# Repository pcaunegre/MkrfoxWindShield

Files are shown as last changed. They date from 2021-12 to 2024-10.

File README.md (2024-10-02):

# MkrfoxWindShield
Arduino Mkrfox1200 interface to wind sensors

## About this project
    
OpenWindMap is a network of wind sensors (https://www.openwindmap.org), 
collecting data from the devices via the Sigfox network.

This project is about building a device (hardware and software) to process 
the measurements from commercial wind sensors and send data via Sigfox 
messages (8 bits every 10min). The device is powered by a small battery and
a solar panel (power management is included on the shield).

This project has a broader scope than the former one (https://github.com/pcaunegre/SWiM) because:
- it supports 3 types of commercial sensors
- it includes a Printed Circuit Board (PCB) design to go as a shield for the Arduino Mkrfox1200
  so that the complete device can be quickly assembled without soldering 

I have a few shields left that I can distribute upon request (pascal.caunegre AT gmail.com)

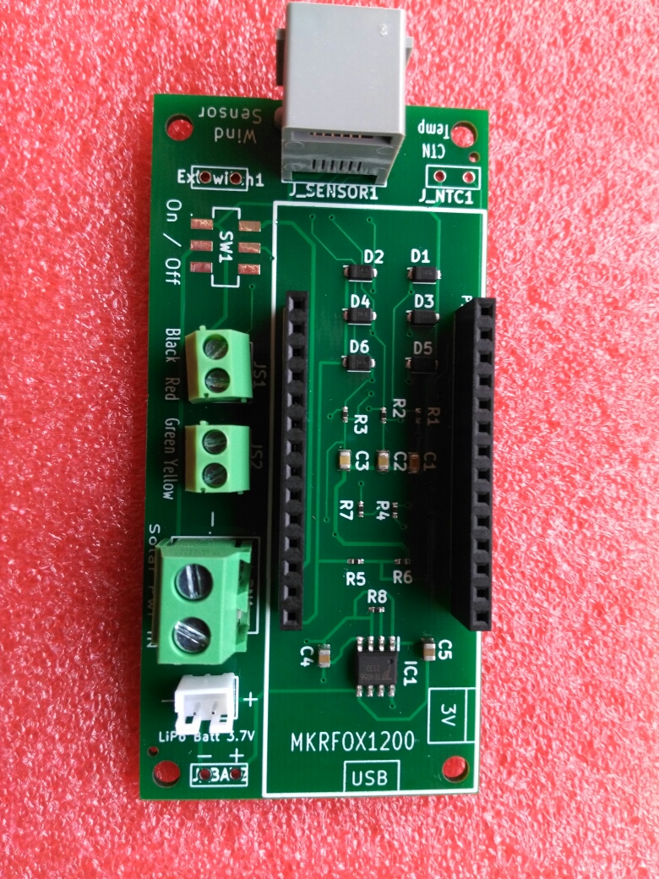
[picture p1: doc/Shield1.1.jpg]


## This project includes several independant modules:

### Hardware
    
The hardware is an Arduino shield compatible with the MKRFOX1200 board.
All material (schematics, layout, docs) are provided here.
The shield provides an interface with one among three types of wind sensors:
- Davis
- Peet Bros
- MiSol (Shenzen)

### Software 
    
The software automatically identifies the sensor type, controls the wind sensor 
and sends measures via Sigfox.
If the device is registered by the OpenWindMap network, measures will appear 
on the web (http://www.openwindmap.org/)

Please read the [manual](doc/Manual.pdf) for more information.

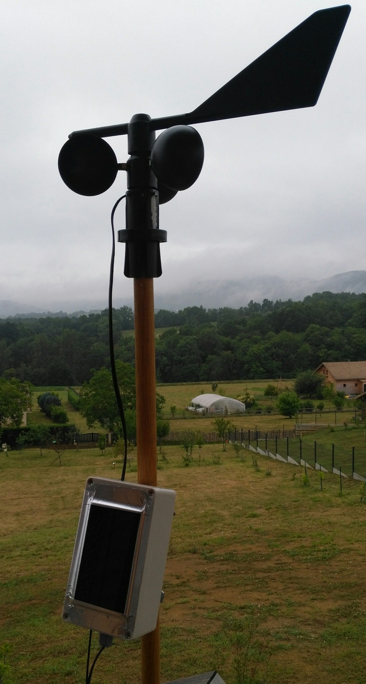
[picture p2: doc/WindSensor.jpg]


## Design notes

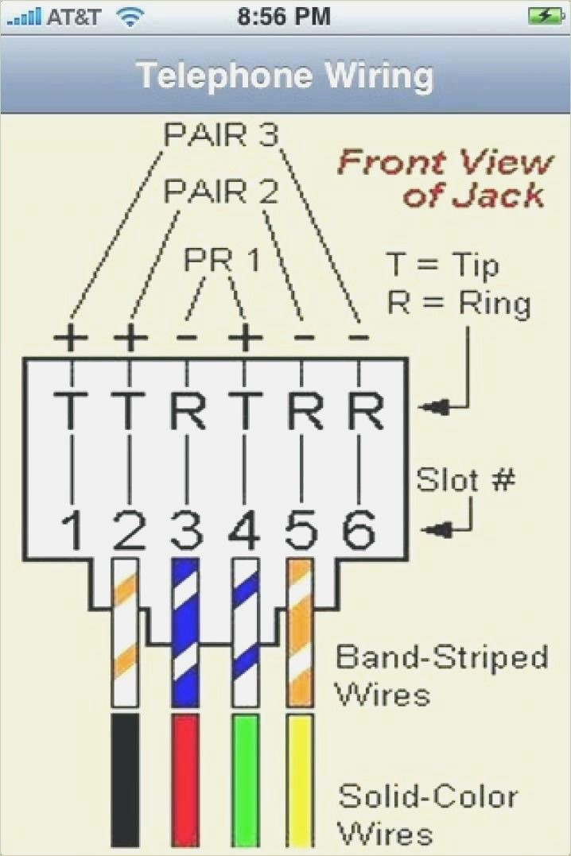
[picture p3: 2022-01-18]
doc/6RJ11.jpg

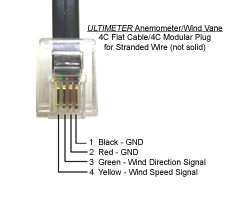
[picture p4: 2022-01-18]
doc/PeetConn.png

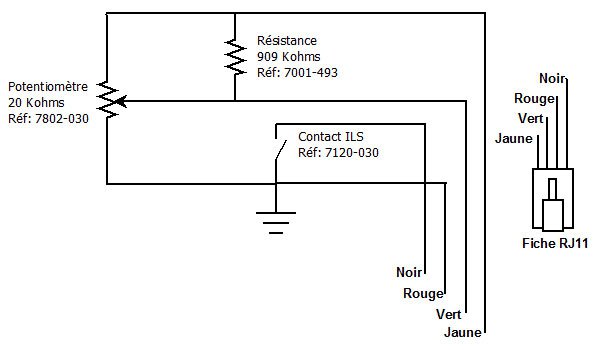
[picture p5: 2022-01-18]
doc/DavisConn.jpg

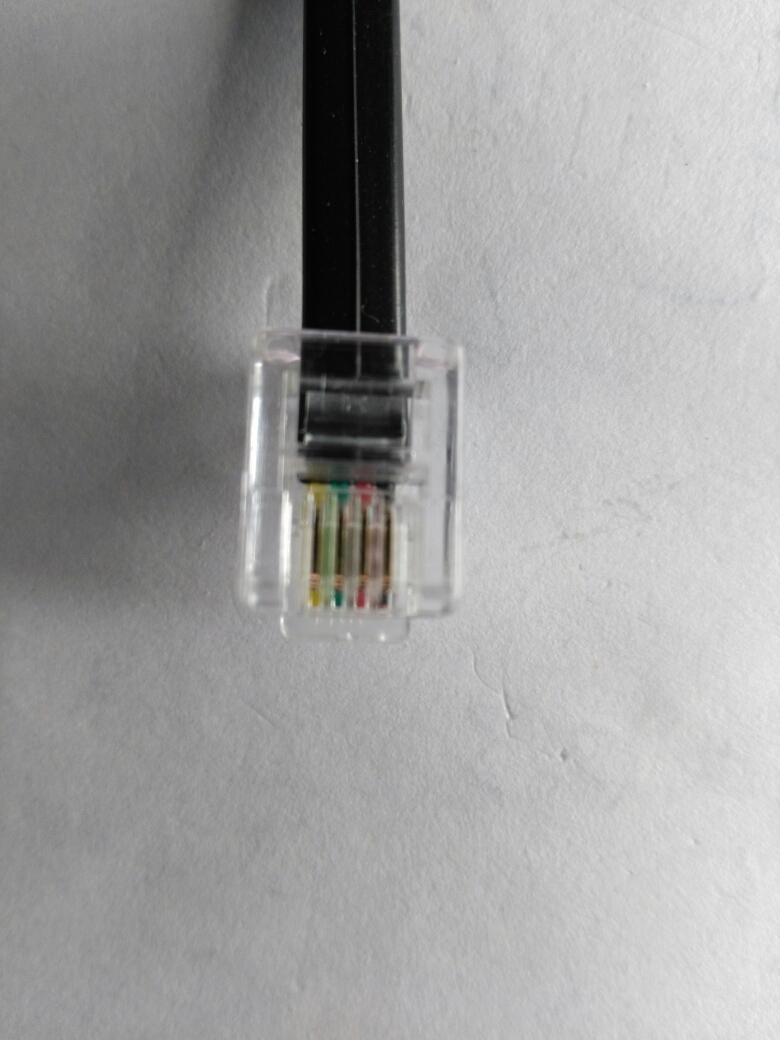
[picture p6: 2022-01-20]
doc/RJ11.jpg

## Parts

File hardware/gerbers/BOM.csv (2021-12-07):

Comment | Designator | Footprint | LCSC Part Number | MFR part number
10nF 10% 50V | C1,C2,C3 | 0805 | C1710 | CL21B103KBANNNC | SMD
10uF 10% 16V | C4,C5 | 0805 | C95841 | CL21B106KOQNNNE
Diode schottky 40V 1A | D1,D2,D3,D4,D5,D6 | SOD-123 | C169540 | 1N5819W
TP4056-42-ESOP8 | IC1 | ESOP-8_EP_3.9x4.9x1.27P | C16581 | TP4056-42-ESOP8
1k 1% 1/16W | R1,R2,R3 | 0402 | C11702 | 0402WGF1001TCE
10k 1/16W 1% | R4,R7 | 0402 | C25744 | 0402WGF1002TCE
390k 1% 1/16W | R5 | 0402 | C25782 | 0402WGF3903TCE
100k 1/16W 1% | R6 | 0402 | C25741 | 0402WGF1003TCE
20k 1/16W 1% | R8 | 0402 | C25765 | 0402WGF2002TCE
Switch 6V 300mA | SW1 | SMD | C221666 | JS202011SCQN
P=3.5mm Screw terminal | JS1,JS2 | CONN-TH_P3.50_KF350-3.5-2P | C474892 | KF350-3.5-2P | Hand soldered
2.54mm 14 Straight 1 Receptacle Through Hole | P1,P2 | HDR-TH_14P-P2.54-V | C124407 | B-2200S14P-A120
2 Header PH 0.079"(2.00mm) Male Pin Through Hole Wire To Board | J_BAT1 | CONN-TH_PH-2A | C8886 | PH-2AK
P=5.08mm Screw terminal | J_PV1 | CONN-TH_2P-P5.00_WJ500V-5.08-2P | C8465 | WJ500V-5.08-2P
DS1133-S60APS | J_SENSOR1 | RJ11-TH_PCB-6P6C-90 | C77857 | DS1133-S60APS

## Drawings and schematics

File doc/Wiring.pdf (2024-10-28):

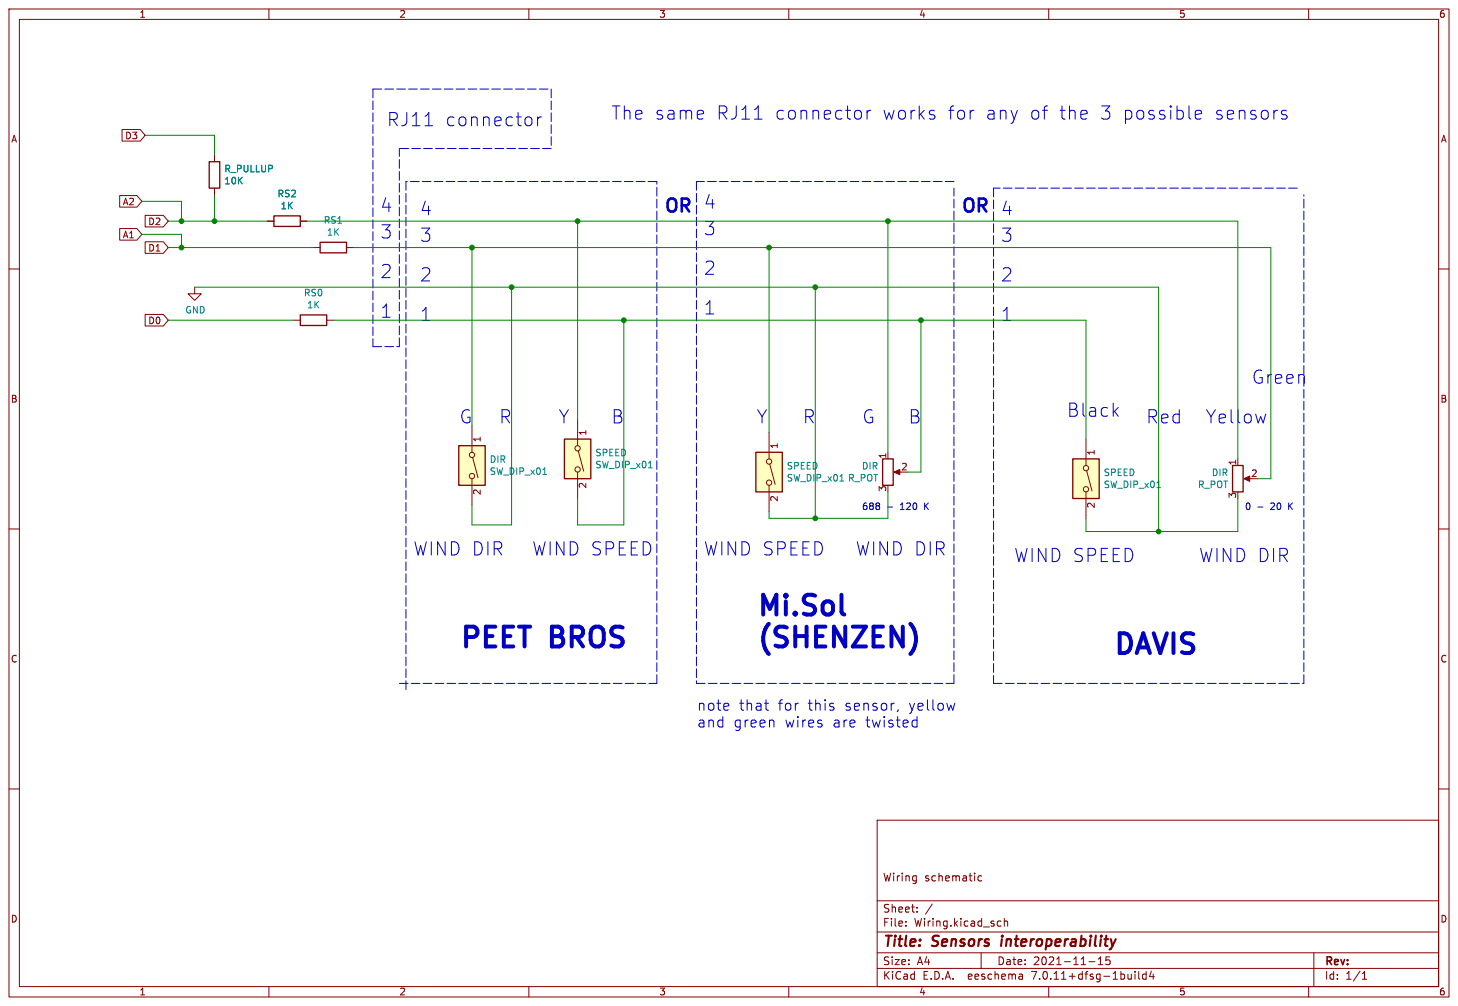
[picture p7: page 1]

File: Wiring.kicad_sch Sheet: / Wiring schematic

Id: 1/1 Title: Sensors interoperability

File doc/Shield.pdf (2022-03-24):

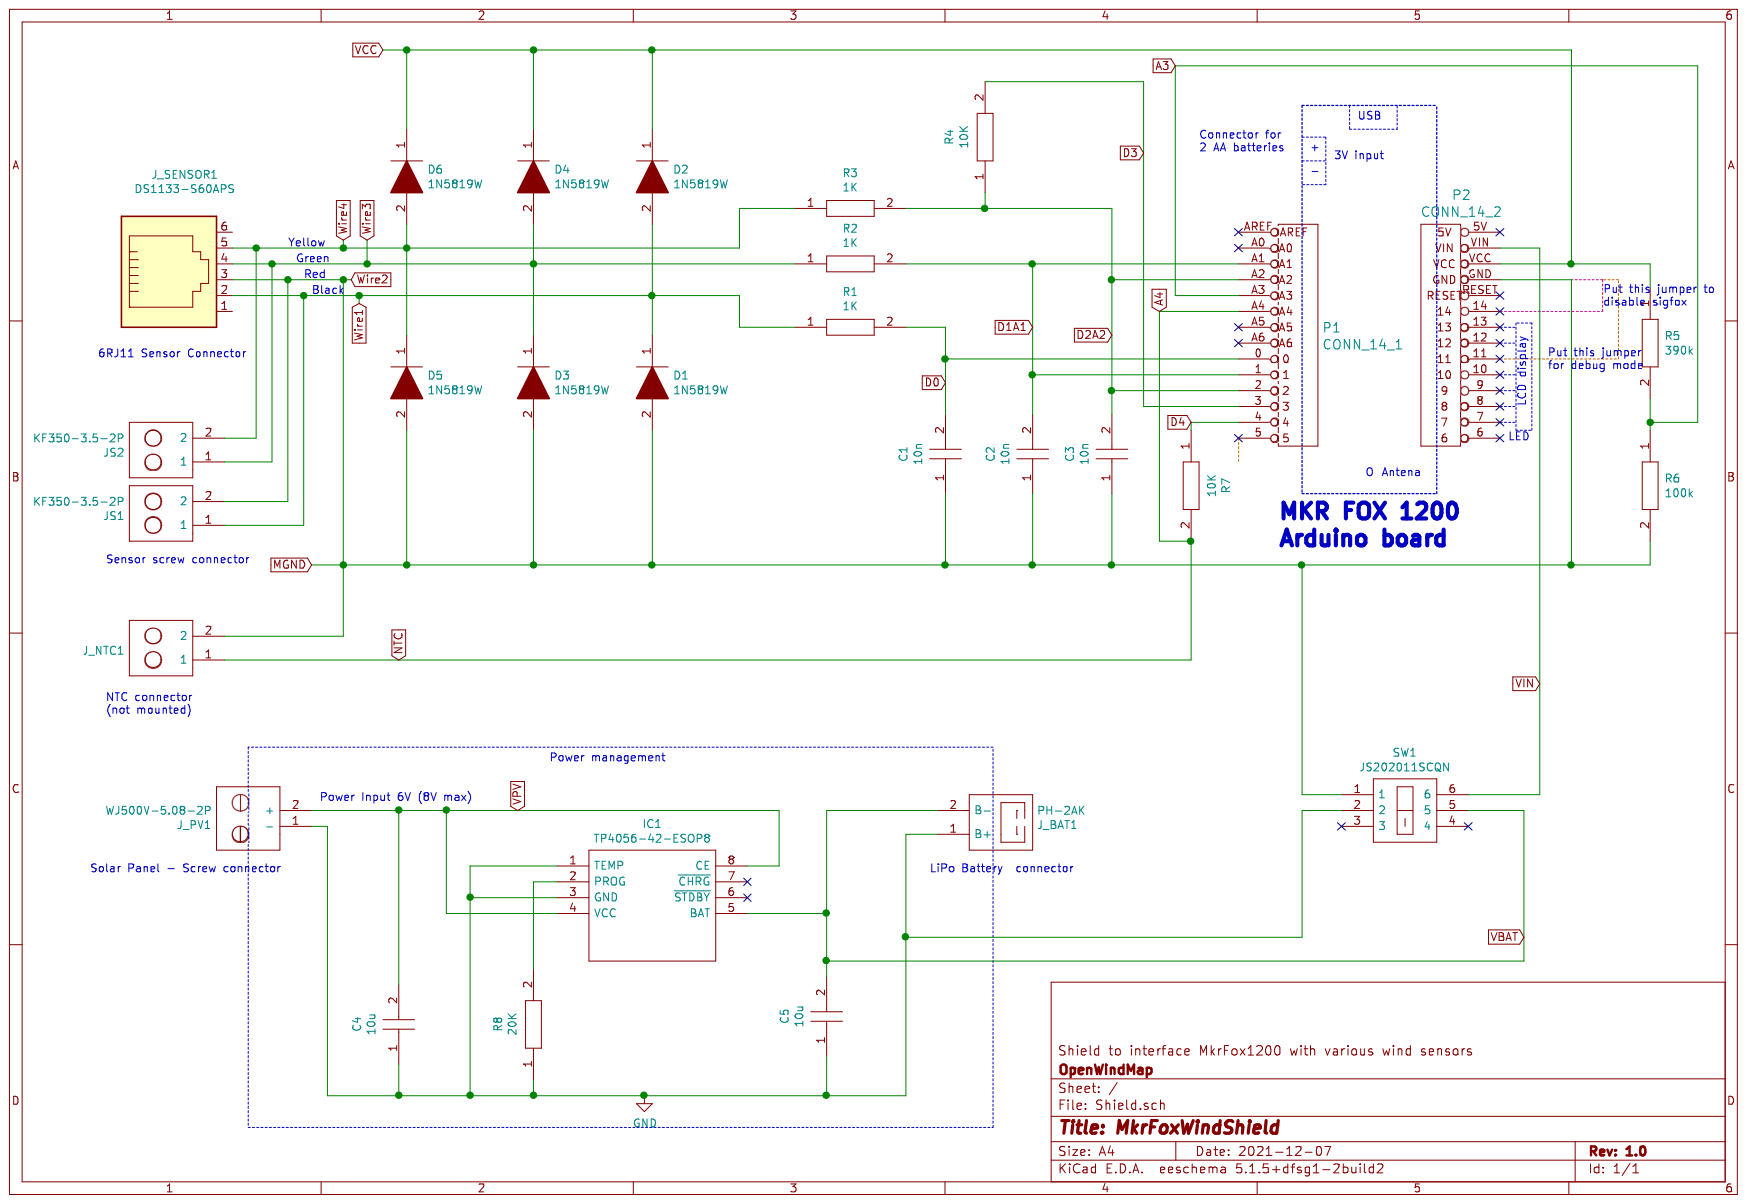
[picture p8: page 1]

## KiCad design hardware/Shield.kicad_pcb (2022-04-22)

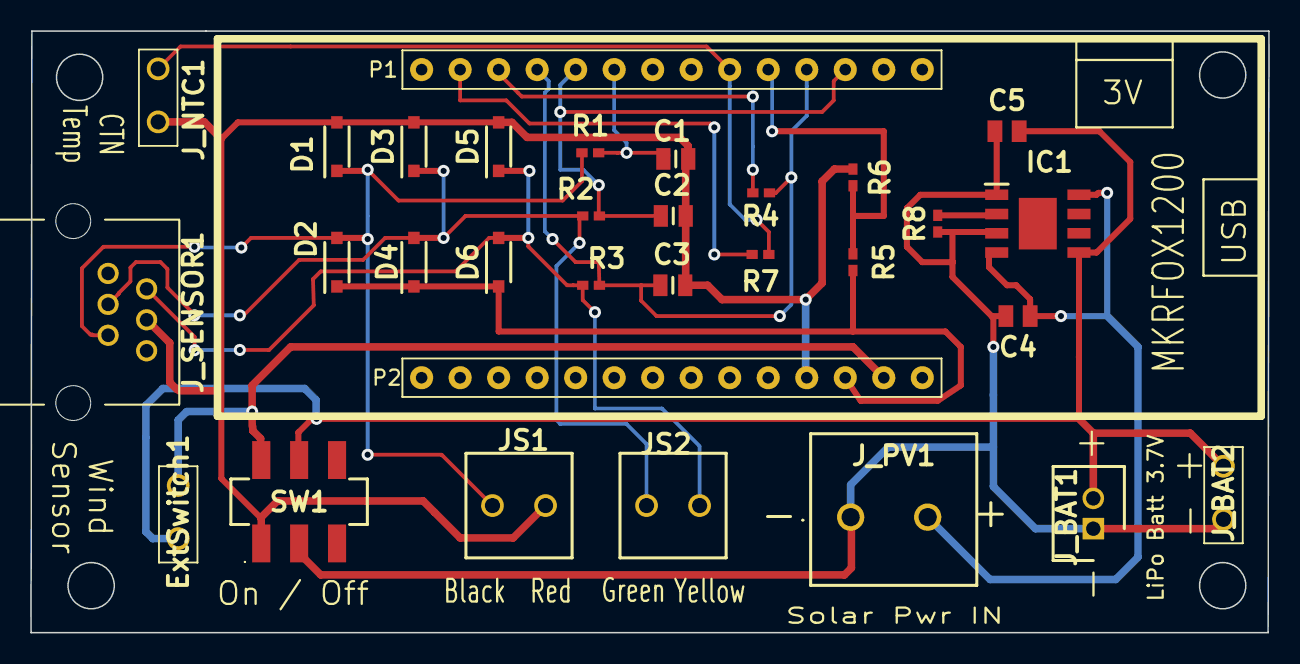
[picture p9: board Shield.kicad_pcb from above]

Board: 2 copper layers, 81.6 x 39.7 mm, 31 parts (0 on the bottom side), 17 nets.

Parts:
C1, C2, C3: 10n; CAPC2012X65N
C4, C5: 10u; CAPC2012X140N
D1, D2, D3, D4, D5, D6: 1N5819W; SODFL3516X120N
ExtSwitch1: KF350-3.5-2P; SolderPoints
IC1: TP4056-42-ESOP8; SOIC127P600X175-9N
JS1, JS2: KF350-3.5-2P; KF350352P
J_BAT1: PH-2AK; SHDR2W52P0X200_1X2_600X460X630P
J_BAT2: KF350-3.5-2P; SolderPoints
J_NTC1: KF350-3.5-2P; SolderPoints
J_PV1: WJ500V-5.08-2P; WJ500V5082P
J_SENSOR1: DS1133-S60APS; DS1133S60APS
P1: CONN_14_1; CONN14_FP1
P2: CONN_14_2; CONN14_FP2
R1, R2, R3: 1K; RESC1005X40N
R4, R7: 10K; RESC1005X40N
R5: 390k; RESC1005X40N
R6: 100k; RESC1005X40N
R8: 20K; RESC1005X40N
SW1: JS202011SCQN

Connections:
A3: P1.A3, R5.2, R6.1
A4: J_NTC1.1, P1.A4, R7.2
D0: C1.2, P1.0, R1.2
D1A1: C2.2, P1.1, P1.A1, R2.2
D2A2: C3.2, P1.2, P1.A2, R3.2, R4.1
D3: P1.3, R4.2
D4: P1.4, R7.1
GND: C4.1, C5.1, IC1.1, IC1.3, J_BAT1.1, J_BAT2.2, J_PV1.1, R8.1, SW1.2
MGND: C1.1, C2.1, C3.1, D1.2, D3.2, D5.2, JS1.2, J_NTC1.2, J_SENSOR1.3, P2.GND, R6.2, SW1.1
unnamed: IC1.2, R8.2
VBAT: C5.2, ExtSwitch1.2, IC1.5, J_BAT1.2, J_BAT2.1, SW1.5
VCC: D2.1, D4.1, D6.1, P2.VCC, R5.1
VIN: ExtSwitch1.1, P2.VIN, SW1.6
VPV: C4.2, IC1.4, IC1.8, J_PV1.2
Wire1: D1.1, D2.2, JS1.1, J_SENSOR1.2, R1.1
Wire3: D3.1, D4.2, JS2.1, J_SENSOR1.4, R2.1
Wire4: D5.1, D6.2, JS2.2, J_SENSOR1.5, R3.1

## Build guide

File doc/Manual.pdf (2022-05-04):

# MkrfoxWindShield manual

pascal.caunegre@gmail.com, Mai 4, 2022

## Building your own wind sensor station

This manual shows how to build an OpenWindMap-compatible wind station.
Refer to https://www.openwindmap.org for more information on this network (previously known as Pioupiou).

## You will need to gather the following parts:

- One of the three possible sensors:

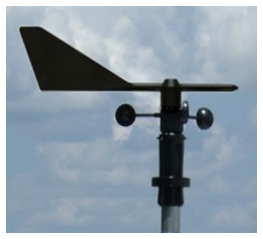
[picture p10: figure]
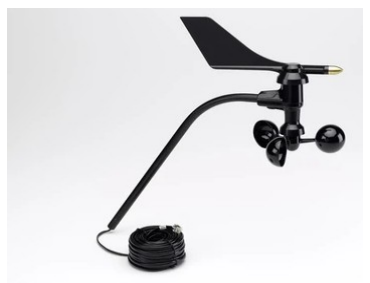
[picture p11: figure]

- The MkrfoxWindShield (version 1.1 on the picture)

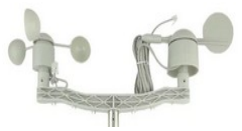
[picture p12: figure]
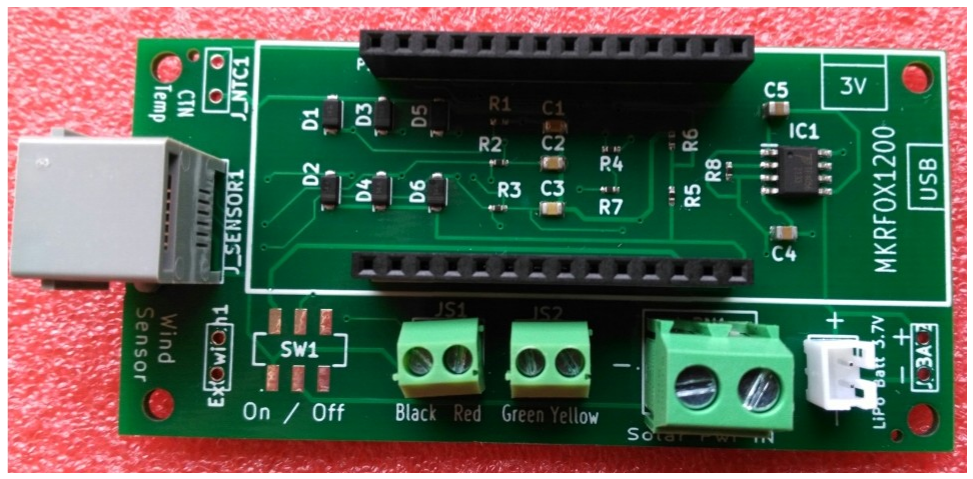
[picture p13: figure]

(the author can resell some boards if available, otherwise you can fabricate them with schematics and part list given in hardware/ directory of this project)

Davis | Peet Bros | Mi.Sol (Shenzen)

OR

OR

- A MkrFox1200 Arduino board

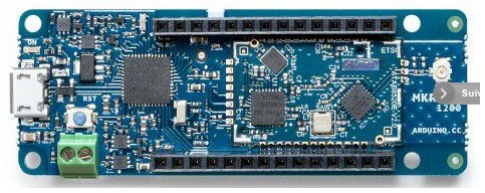
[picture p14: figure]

- A 868 Mhz Antenna
- Either batteries or solar panel

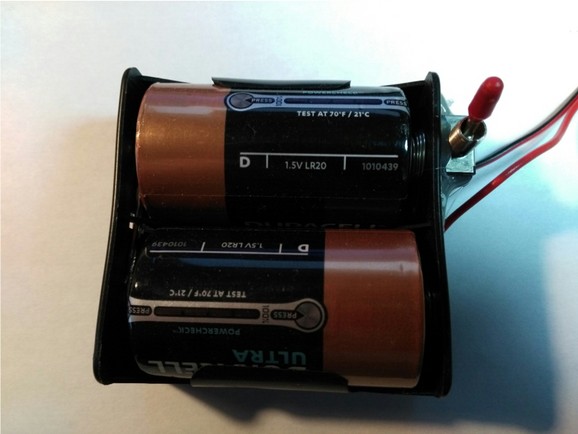
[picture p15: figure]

(note: 1.5V batteries will last about a year while solar panel solution will not need maintenance)

## Uploading the station software

Your MkrFox1200 needs a software to operate the wind sensor. But first you need to read internal board IDs with a specific program. Process as follows:

- If necessary, install the Arduino software (IDE) on your computer.
- Download all code files from the github: https://github.com/pcaunegre/MkrfoxWindShield/tree/main/src/firmware
- Connect the board to your computer by a USB cable

Board ID reading:
- Open the src/board_infos/board_infos.ino file from the IDE
- Double click on the board reset button, the yellow led is dimmed and blinks, meaning the board is ready to receive the program
- Click the upload button from the IDE
- Open the Serial monitor
- The ID and PAC values will be printed. Note them down.

A set of two 1.5V Batteries

OR

A Solar Panel (5V, 0.5W) + a LiPo 3.7V battery

Registration of the board through OpenWindMap network
Send the board IDs you have noted down to OpenWindMap through the forum.
You will get a station ID in return.
Your measurements will be available through http://www.openwindmap.org/<ID>
Note: it is important to register the board via OWM (and not directly via Sigfox server) because it allows benefiting the group contract and shares your measurements with the community.

Final software installation:
Important: Don’t do this before your station is registered in OpenWindMap because this step will trigger a Sigfox message dispatch. (Alternately, you can put a jumper between the pin GND and pin 14 to disable the Sigfox messages.)
- Open the src/firmware/firmware.ino file from the IDE
- Double click on the board reset button, the yellow led is dimmed and blinks, meaning the board is ready to receive the program
- Click the upload button from the IDE
- The led should then blink frankly 10 times and then switch off.
- Your board is ready, disconnect it from USB.

## Assembling parts

Assemble the various parts and install them into a rainproof box. To assemble you will have to:
- Plug the MkrFox1200 on top of the wind shield.
- Connect the antenna through the coaxial RF socket.
- If you use 1.5V batteries, connect them through the MkrFox1200 screw connector (take care of the polarity). Preferably use solar panel+Lipo battery, by connecting them on the wind shield (solar panel on screw connector, battery on the white socket).
- Connect your wind sensor either by plugging the RJ11 jack or by connecting the wires by the screw connector (from left to right):
- for Davis and Peet sensors: connect 1: black wire, 2: red, 3: green, 4: yellow
- for MiSol: | connect 1: black wire, 2: red, 3: yellow, 4: green

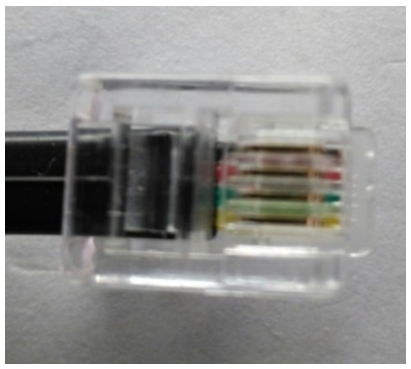
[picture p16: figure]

Notes about v1.1 of the board

- There are 2 holes to solder an external switch (in this case, do a solder point between the pads above the “on” mark)
- There are 2 holes to solder the battery (instead of using the connector)
- J_NTC1 is to solder a 10k NTC for optional temperature measurement (but software get temperature only
once a day)

## Starting the wind sensor

Now that all components are connected together, let’s switch on the system.
- If using the Lipo battery, turn the shield switch on
- If using 1.5V batteries the power is on as soon as you place the batteries in their harness The board will boot and you will see 10 flashes of the yellow led.
Then you will see 1, 2 or 3 long flashes. They mean that the system identifies your sensor.
1 flash means Davis sensor, 2 flashes means Peet sensor, and 3 flashes means MiSol sensor.
If the sensor recognition is wrong, the led desperately blinks. Verify the sensor connection, move a bit the wind vane position and push the reset button.
If the led keeps blinking, this means that the sensor is wrongly connected or the sensor type is not recognized or has any default.
The sensor starts immediately the measurements (1 measure every 3s). Every 5 minutes, minimum, maximum and average wind speed and average wind direction values are computed. After 10 minutes, the 2 sets of previous measurements are send to Internet via Sigfox network.
It means that 10 min after power up you should see your measurements on OpenWindMap site.
SpotAir (https://www.spotair.mobi) will also reflect the same measurements after a little time (about a day) without any action from you.

## Debug mode

You can put a jumper between GND and Pin 11 to enter the debug mode. In this mode, if you connect the board via the USB cable and read the USB input from your computer, the measurements will be printed. To read the USB input, use the serial monitor from the Arduino IDE.
If you want to capture values in a file, you can use this Python script: __________________________________________________________________________

#!/usr/bin/python3

## Script to listen serial port and write contents into a file for debug purpose

## requires pySerial to be installed ( pip3 install pyserial )

# call it

# serialListen.py [ <filename.csv> ]

import serial
from datetime import datetime import sys
import time

now = datetime.now()
dt_string = now.strftime("%H:%M")

n=len(sys.argv)
if n>1:
write_to_file_path=sys.argv[1]
else:
write_to_file_path = "Imeas" + dt_string +".csv"

serial_port = '/dev/ttyACM0';
baud_rate = 9600; #In arduino, Serial.begin(baud_rate)

output_file = open(write_to_file_path, "w+")

while True:
try:
ser = serial.Serial(serial_port, baud_rate) break
except:
time.sleep(1)

while True:
line = ser.readline();
line = line.decode("utf-8") #ser.readline returns a binary, convert to string print(line);
output_file.write(line)
output_file.flush()
__________________________________________________________________________

## Admin reports

When you switch on the wind sensor and once a day, an admin report is sent.
The admin report can be seen here: https://api.pioupiou.fr/v1/sigfox-messages/<ID>
An admin report is a data of 12 bytes, e.g.:

Only the 4 last bytes (8 characters) encode the admin report with the following infos:
byte 9 | : | battery voltage (by adding 199.5 and dividing by 100)
byte 10 | : | temperature ( by substracting 50.5)
byte 11 | : | sensor type (10=Davis, 20=Peet bros, 30=MiSol Shenzen)
byte 12 | : | software version

Example of python script to decode the admin report: #!/usr/bin/python3
import sys
entry=sys.argv[1]
print("Soft = %d" % int(entry[22:24],16))
print("Sensor = %d" % int(entry[20:22],16))
print("Temp = %d" % (int(entry[18:20],16)-50.5)) print("Vbatt = %f" % ((int(entry[16:18],16)+199.5)/100.0))

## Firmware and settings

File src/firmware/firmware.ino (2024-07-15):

/*
*
*  Main program to control the MKRFOX 1200 board
*
*  Able to interface with Davis, Peet Bros or Shenzen device.
*
*
*
*/

#include <SigFox.h>
#include <math.h>
#include "def.h"



unsigned long  last_sampleT  ;  // last time in millis a measure sampling has been done
unsigned long  last_reportT  ;  // last time in millis a report has been done

int            max_wspeed    ;  // max wind speed over the sample period
int            min_wspeed    ;  // min wind speed over the sample period
int            cnt_ws_samples;  // count the number of samples we have to compute speed avg
int            cnt_wd_samples;  // count the number of samples we have to compute dir avg
int            acc_wspeed    ;  // wind speed accumulator to compute avg
float          acc_wdX       ;  // accumulate wind dir projection on X axis (cos)
float          acc_wdY       ;  // accumulate wind dir projection on X axis (sin)
int            prevWindDir   ;  // memorize the last dir in case we cannot compute new one (speed too low)
int            statReportCnt ;  // counter : every 2 hits data are sent thru sigfox 
SigfoxWindMessage_t msg      ;  // create an instance of the struct to receive the wind data frame
int            sentrepnbr=0  ;  // nbr of report sent

float          vinMax=0.0    ;  // max VCC voltage over a daily period
float          vinMin=0.0    ;  // min VCC voltage over a daily period
float          tmpMax=0.0    ;  // min Temperature over a daily period
float          tmpMin=0.0    ;  // min Temperature over a daily period
float          vinSum=0.0    ;  // sum of VCC voltage over a daily period
float          tmpSum=0.0    ;  // sum of Temperature over a daily period
int            mdCnt=0       ;  // nbr of monitoring elements
int            firstsmp=1    ;  // first sample token

int            cpudiv        ;  // value of cpu freq divisor

bool           debugmode = false; // 1=debug mode
bool           sigfox_en = true ; // enable sigfox
int            repnbr=0;          // used in debug
int            msnbr=0;           // used in debug
int            monitoringReportNbr=0; // number of sent monitoring report

int sensor=0;          // sensor number


void setup() {
  
  int blinknbr=SOFTVERSION; // e.g. blinks 12 times for version 1.2
  // a jumper between 12 and GND will disable sigfox
  pinMode(SIGDISAB,INPUT_PULLUP); 
  sigfox_en = digitalRead(SIGDISAB);

  // a jumper between 10 will enable led blink
  pinMode(TESTPIN,INPUT_PULLUP); 

  cpudiv = CPU_FULL;
  
  // a jumper between 11 and GND will enable debug mode
  pinMode(DEBUGPIN,INPUT_PULLUP); 
  pinMode(Led,OUTPUT); // led used for debug or at power up
  
  if (digitalRead(DEBUGPIN) == 0) {
    debugmode=true;  
    blinkLed(5,400/cpudiv); // blinks 5 times to indicate debug mode
    delay(3000);    // waiting 3s to allow launching usb serial on PC
  }

  debugInit(sigfox_en,debugmode);
  blinkLed(blinknbr,400/cpudiv); // say hello n flashes

    
  // device detection at boot
  if (sensor == 0) {
    delay(3000);
    detectSensorType();  // will set the sensor variable
  } 
  
  // device initialization
  switch (sensor) {
    case DAVIS:
      Davis_setup();    break;
    case PEET:
      Peet_setup();     break;
    case SHENZEN:
      Shenzen_setup();  break;
    default:
      // say detection failed: blink 1000 times and reboot
      blinkLed(1000,500/cpudiv);
      reboot();
  }
  sendInitialReport();
  statReportCnt    = 0;
  prevWindDir      = -1;
  repnbr           = 0;
  reset_stat(); 
  if (!debugmode) set_cpu_speed(CPU_SLOW);
  last_sampleT     = millis();
  last_reportT     = millis();
  sentrepnbr=0;
    
}


void loop() {

  if (sensor>0) {
    
    // normal operation
    unsigned long now = millis();
    unsigned long dt1 = now - last_sampleT;  // ellapsed time since last sample
    unsigned long dt2 = now - last_reportT;  // ellapsed time since last report
    
    // if it's time to sample, get measures and store for stats
    if (dt1 > SAMPLING_PERIOD/cpudiv) {
      noInterrupts();
      int ws  = -1;
      int wd  = -1;
      switch (sensor) {
        case DAVIS:
          ws=Davis_takeWspeed(dt1);
          wd=Davis_takeWdir();
          break;
        case PEET:
          ws=Peet_takeWspeed();
          wd=Peet_takeWdir();
          Peet_resetSampler();       
          break;
        case SHENZEN:
          ws=Shenzen_takeWspeed(dt1);
          wd=Shenzen_takeWdir();        
          break;
        default:
          // NOT initialized: run init procedure
          // TBD
          break;
      }
      // drop out the first sample
      if (firstsmp==0) store_for_stat(ws,wd);
      firstsmp=0; 
      debugPrintMeasure(ws,wd);         
      // when pin low, led blinks to show activity
      if (digitalRead(TESTPIN)==0) { blinkLed(1,300/cpudiv); } 
      last_sampleT = millis();
      interrupts();
    }
    
    if (dt2 > (REPORT_PERIOD/2)/cpudiv) {
      // at every sigfox report period we send 2 packets of data
      // so at every half-report period we store data     
      if (digitalRead(TESTPIN)==0) { blinkLed(2,300/cpudiv); }  
      makeReport();
  
      // clear stats
      reset_stat();
      last_reportT = millis();
      last_sampleT = millis();
    }

    if (now > REBOOT_PERIOD/cpudiv) {
      debugPrintMsg("REBOOTING");
      reboot(); // avoid managing millis value wrapping (every 2**32-1 ms)
    }
  }  

}

/*
 * Take measures and compute some statistics over a report period
 * min, max, accumulate for average, mean wind dir
 * 
*/
void store_for_stat(int ws, int wd)  {
  // wind speed in km/h
  // wind dir in degrees
  // -1 means meas not valid  
  if (ws>-1)  {
    if (ws > max_wspeed)  max_wspeed = ws;
    if (ws < min_wspeed)  min_wspeed = ws;
    acc_wspeed += ws;
    cnt_ws_samples++;
  
    if (wd>-1)  {
      // projection of direction is weighted by the speed
      acc_wdX += ws * cos(PI*wd/180.);
      acc_wdY += ws * sin(PI*wd/180.);
      cnt_wd_samples++;
    }
  } 
}

/*
 * Resets all counters and accumulator when a report has been done
 * min, max, accumulate for average, mean wind dir
 * 
*/
void reset_stat()  {
  max_wspeed    = 0  ;
  min_wspeed    = 999;
  acc_wspeed    = 0  ;
  cnt_ws_samples= 0  ;
  cnt_wd_samples= 0  ;
  acc_wdX       = 0.0;
  acc_wdY       = 0.0;
  firstsmp      = 1;
}

/*
 * Computes avg wind speed
*/
int wspeed_avg()  {
  SERIAL.print("sum WS =");SERIAL.println(acc_wspeed);
  SERIAL.print("Nbr WS =");SERIAL.println(cnt_ws_samples);
  
  //debugPrint("sum WS =",acc_wspeed);
  //debugPrint("cnt WS =",cnt_ws_samples);
  return(int(acc_wspeed/cnt_ws_samples));
}

/*
 * Computes avg wind direction
*/
int wdir_avg()  {    
  int avgdir;
  // when no dir samples, keep the previous direction
  if (!cnt_wd_samples) return(prevWindDir);

  if (acc_wdY==0.0 && acc_wdX==0.0)  {
    // when speed is null over the whole period, we cannot compute the avg direction
    avgdir=prevWindDir;
  } else {
    avgdir = int(atan2(acc_wdY,acc_wdX)*180/PI);
    if (avgdir<0)  avgdir += 360;
    prevWindDir = avgdir;   // store this in a globvar
  }  
  return(avgdir);
}

/*
*
*  Data Report creation/dispach
*
*/
void makeReport() {

  int avws, avwd, ret;

  noInterrupts();
  debugPrintMsg ("Report ");
  storeMonitoringData();
    
  // report the values
  avws = wspeed_avg();
  avwd = wdir_avg();
  debugPrintAvgMeas(avws,avwd);
  
  // store in msg structure with OpenWindMap-expected data encoding
  msg.speedMin[statReportCnt]     = encodeWindSpeed(min_wspeed);
  msg.speedAvg[statReportCnt]     = encodeWindSpeed(avws);
  msg.speedMax[statReportCnt]     = encodeWindSpeed(max_wspeed);
  msg.directionAvg[statReportCnt] = encodeWindDirection(avwd); 
  
  SERIAL.print("msg Min (");SERIAL.print(statReportCnt);SERIAL.print(") = ");SERIAL.println(min_wspeed);
  SERIAL.print("msg Avg (");SERIAL.print(statReportCnt);SERIAL.print(") = ");SERIAL.println(avws);
  SERIAL.print("msg Max (");SERIAL.print(statReportCnt);SERIAL.print(") = ");SERIAL.println(max_wspeed);
  SERIAL.print("msg DIR (");SERIAL.print(statReportCnt);SERIAL.print(") = ");SERIAL.println(avwd);
    
  interrupts();

  // we send telegram half the time
  if (statReportCnt==1) {
    // every ADMIN_REPORT_FREQ reports, we send a monitoring report
    statReportCnt=0;
    if (sentrepnbr >= ADMIN_REPORT_FREQ) {
      sentrepnbr = 0;
      addMonitoringInfos();
      ret=sendSigFoxMessage(12);
      debugPrint("  Monitoring rep sent: ",ret);
    } else {
      // send sigfox telegram this time
      debugPrint("Make Rep NBR = ",sentrepnbr);
      ret=sendSigFoxMessage(8);
      sentrepnbr++;
      debugPrint("  Normal report sent: ",ret);
    }
  } else {
    // sigfox telegram will be next turn
    statReportCnt=1;
    debugPrintMsg("  Next time");
  }

}

/*
*
*  get and store Vin and Temp measures for monitoring report
*
*/
void storeMonitoringData() {
  float vin=getBatteryVoltage(VINMEAS);
  float tmp=getTemperature();
  vinSum += vin;
  tmpSum += tmp;
  if (vin>vinMax) vinMax=vin;  
  if (vin<vinMin) vinMin=vin;  
  if (tmp>tmpMax) tmpMax=tmp;  
  if (tmp<tmpMin) tmpMin=tmp;
  mdCnt++;      
}

/*
*  reset variables used by monitoring report
*/
void clearMonitoringData() { 
  vinMax=0.0;  vinMin=9999; vinSum=0.0;
  tmpMax=-99;  tmpMin=99;   tmpSum=0.0;
  mdCnt=0;      
}

/*
*  add supplementary infos into report for monitoring purpose
*
* Data:   vinMax vinMin vinAvg tmpMax tmpMin tmpAvg nbr   notused VIN   VCC   TEMP  SENS+SoftV 
* Bytes:  1,2    3,4    5,6    7,8    9,10   11,12  13,14 15,16   17,18 19,20 21,22 23,24 
*/
void addMonitoringInfos() {

  // include stat infos collected over the period
  // by using the 8 first bytes for different purpose
  monitoringReportNbr++; 
  msg.speedMin[0] = encodeVoltage(vinMax);
  msg.speedMin[1] = encodeVoltage(vinMin);
  msg.speedAvg[0] = encodeVoltage(vinSum/mdCnt);
  msg.speedAvg[1] = encodeTemperature(tmpMax);
  msg.speedMax[0] = encodeTemperature(tmpMin);
  msg.speedMax[1] = encodeTemperature(tmpSum/mdCnt);
  msg.directionAvg[0] = mdCnt;
  msg.directionAvg[1] = monitoringReportNbr; 
  clearMonitoringData(); // reset the values
  
  float vcc=getBatteryVoltage(VCCMEAS); // measure VCC (when 3V battery is used)
  // not possible with hardware h1.1: 
  // requires 390k resistor between VIN and A5 + 100k between A5 and GND
  float vin=getBatteryVoltage(VINMEAS); // measure VIN (real Lipo batt voltage)
  float  tp=getTemperature();

  msg.batVin      = encodeVoltage(vin);    // VIN measure (if wired)
  msg.batVcc      = encodeVoltage(vcc);    // VCC measure
  msg.temperature = encodeTemperature(tp); // Temperature (if sensor wired)
  // encode sensor+softversion in one Byte : b = s<<6 + v
  // 2 bits for sensor, 6 bits for softversion 
  // decode with s=b>>6, v=b&63
  msg.version     = (uint8_t)((sensor/10)<<6)+SOFTVERSION; // Sensor type DAVIS=10 PEET=20 MISOL=30 
  
  debugPrint("batVin  ",(uint8_t)msg.batVin);
  debugPrint("batVcc  ",(uint8_t)msg.batVcc);
  debugPrint("temp    ",(uint8_t)msg.temperature);
  debugPrint("version ",(uint8_t)msg.version);
  debugPrint("Admin RPT",sensor);
}


/*
*  send the monitoring message at reboot
*/
void sendInitialReport() { 
  // dummy values for init for easy message retrieving
  msg.speedMin[0]     = 0;  msg.speedMin[1]     = 0;
  msg.speedAvg[0]     = 0;  msg.speedAvg[1]     = 0;
  msg.speedMax[0]     = 0;  msg.speedMax[1]     = 0;
  msg.directionAvg[0] = 0;  msg.directionAvg[1] = 0;
  addMonitoringInfos();
  int ret=sendSigFoxMessage(12);  // send initial monitoring report
  debugPrint("Initial rep sent: ",ret);
  SERIAL.println(millis());
}
    
/*
*  Utility to find out which sensor is connected
*  period in millis
*
*/
void blinkLed(int times, int period) {
  for (int i=0; i<times; i++ ) {
    digitalWrite(Led,HIGH);
    delay(period);
    digitalWrite(Led,LOW);
    delay(period);
  } 
}

/*
 * system functions
*/
void reboot() {
  NVIC_SystemReset();
  while (1);
}

/*
 * CPU underclocking: clock is divided by divisor
*/
void set_cpu_speed(int divisor){
  cpudiv=divisor;
  GCLK->GENDIV.reg = GCLK_GENDIV_DIV(divisor) |         // Divide the 48MHz clock source by divisor 48: 48MHz/48=1MHz
                   GCLK_GENDIV_ID(0);            // Select Generic Clock (GCLK) 0
  while (GCLK->STATUS.bit.SYNCBUSY);               // Wait for synchronization      
}

/*
*
*  Utility to find out which sensor is connected
* 
*  We power up the lines through 2 configurations and measure the analog value on A2
*  Based on the resistor dividers, tolerances, we have thresholds to identify the sensor.
*
*/
void detectSensorType() {
  
  String mess="";
  analogReadResolution(ADCBITS);
  analogReference(AR_DEFAULT);
  pinMode(SENSPPIN,OUTPUT); // sensor potentiommeters are powered by this pin
  digitalWrite(SENSPPIN,HIGH);
    
  // step 1 : D2R, D0R
  pinMode(2,INPUT);
  pinMode(0,INPUT);
  delay(500);
  int val1 = analogRead(A2);
 
  // step 2 : D2R, D0W0
  pinMode(2,INPUT);
  pinMode(0,OUTPUT);
  digitalWrite(0,LOW);
  delay(500);
  int val2 = analogRead(A2);
  
  //stop powering sensor
  pinMode(0,INPUT_PULLUP);
  digitalWrite(SENSPPIN,LOW);

  if (val1 > THR1)  {
    // can be shenzen or peet
    if (val2 > THR1) { 
      // we have peet sensor
      sensor=PEET;
      blinkLed(sensor/10,1500/cpudiv); // say Peet detected
    } else if ((val2 > THR_Shenzen_low) && (val2 < THR_Shenzen_hi)) {
      // confirm we have shenzen sensor
      sensor=SHENZEN;
      blinkLed(sensor/10,1500/cpudiv); // say Shenzen detected
    } else if (val2 < THR_Peet_hi) {
      // Peet when dir switch is closed
      sensor=PEET;
      blinkLed(sensor/10,1500/cpudiv); // say Peet detected
    } else {
      sensor=-1;
      mess="Detection issue between shenzen and peet";
    }
    
  } else if ((val1 > THR_Davis_low) && (val1 < THR_Davis_hi)) {
    // confirm we have Davis  
    if ((val2 > THR_Davis_low) && (val2 < THR_Davis_hi)) {
      // val2 should not differ from val1
      sensor=DAVIS;
      blinkLed(sensor/10,1500/cpudiv); // say Davis detected
    } else {
      sensor=-1;
      mess="Detection issue with Davis";
    }
  } else {
    sensor=-1;
    mess="Sensor Detection issue";
  }
  debugSensorDetection(mess,sensor,val1,val2);

}

/*
*  Utility to measure Battery voltage, return mV
*/
float getBatteryVoltage(int vpin) {

  analogReadResolution(ADCBITS);
  analogReference(AR_INTERNAL1V0);
  delay(100);
  float vb=(analogRead(vpin)/(ADCFS*VBDIV))*1000.0; // read vbat through k~1/5 divider so v=adc/(k*adcfs)
  debugPrintVbat(vpin,vb);
  analogReference(AR_DEFAULT);  // restore to the default ref used in other parts of the code
  delay(100);
  return(vb);

}

/*
*  Utility to measure temperature
*/
float getTemperature() {
  
  analogReadResolution(12);      
  analogReference(AR_DEFAULT); // to give a ratio of the resistor divider
  pinMode(4,OUTPUT);
  digitalWrite(4,HIGH);
  delay(100);
  int adc=analogRead(A4);
  
  analogReadResolution(ADCBITS);
  digitalWrite(4,LOW);
  delay(100);
  
  float Rnorm=(1.0/((4095.0/adc)-1.0));    // R pull up of 10k
  float tp=1.0/(log(Rnorm)/BETA+1.0/TEMP25)-273.15; // temp in Celsius
  debugPrintTemp(tp);
  return(tp);

}


/*
 * functions dedicated to Sigfox message sending
 * 
 *speedMin[0], speedMin[1], speedAvg[0], speedAvg[1], speedMax[0], speedMax[1], dirAvg[0], dirAvg[1]
 *
 * message len=8 for a normal measure transmission, 12 for an admin transmission
*/
int sendSigFoxMessage(int len) {

  int status=0; 
  if (digitalRead(SIGDISAB)) {
    debugPrint("Sending SFX Msg ",len);
    set_cpu_speed(CPU_FULL);
    // Start the module  
    delay(10);
    //SigFox.begin();
    if (!SigFox.begin()) {
      debugPrintMsg("SigFox begin error");
//       reboot();
    }
    // Wait at least 30mS after first configuration (100mS before)
    delay(100);
    SigFox.debug();

    // Clears all pending interrupts
    SigFox.status();
    delay(1);
    SigFox.beginPacket();
    
    // OpenWindMap specific data frame  
    SigFox.write((uint8_t*)&msg, len); 
    status = SigFox.endPacket();    
    SigFox.end();
    if (!debugmode) set_cpu_speed(CPU_SLOW);
 
  } else {
    debugPrint("Sigfox disabled ",len);
  }
  return(status);
}

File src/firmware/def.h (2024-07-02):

#define SOFTDATE 20240701
#define SOFTVERSION 22


#define DAVIS       10   // sensor numbering
#define PEET        20   // sensor numbering
#define SHENZEN     30   // sensor number


#define Led LED_BUILTIN  // warning: Led uses pin D6 !
#define ARRAYLEN    120  // size of an array to store pulses (40rps gives 120 values in 3s)

#define CPU_FULL   1     // normal cpu rate (48Mhz)
#define CPU_SLOW   16    // divided by 16 so 3Mhz for power saving, so we have ~3.1mA and a peak of ~45mA during 3s every 10min

// periods in ms and multiple of CPU_SLOW (16)
#define SAMPLING_PERIOD          2992    // instantaneous wind is measured on a 3s period (common rule) so 2992ms to be a modulo 16 (clock divider)
// #define REPORT_PERIOD          600000UL  // in production, report period is 10min=600s (both the period to avg the wind speed and the sigfox report period)
#define REPORT_PERIOD          592000UL  // in production, report period is 10min=600s (both the period to avg the wind speed and the sigfox report period)
#define ADMIN_REPORT_FREQ         143    // after 143 measure reports we send a monitoring report
#define REBOOT_PERIOD         604800000UL  // reboot micro every 7 day

#define VCCMEAS    A3           // Analog Pin to measure VCC voltage
#define VINMEAS    A5           // Analog Pin to measure VIN voltage

#define SERIAL   Serial         // Serial connection for debug
#define DEBUGPIN   11           // Pin to detect debug mode (when low)
#define SIGDISAB   12           // Pin to disable sigfox messages (when low)
#define TESTPIN    10           // Pin to enable led to monitor activity (when low)

#define SENSPPIN   3            // Pin to power up the sensor 
#define RPULLUP    10.0         // Pullup in kOhm
#define RSERIAL    1.0          // Same value for RS1, RS2, RS3 in kOhm
#define ADCBITS    10           // Using default ADC setup is enough
const int ADCFS =  (1<<ADCBITS)-1; // ADC full scale = 2**10-1
#define TOL        0.07          // Tolerance on R values (7%): 5% was not enough

#define VBDIV      0.20         // Res Divider to measure Vbat (100k/(100k+400k))

#define RSHENMIN   0.688        // Min value of Dir Potentiometer (Shenzen sensor) in kOhm
#define RSHENMAX   120.0        // Max value of Dir Potentiometer (Shenzen sensor) in kOhm

#define RDAVISPOT  20.0         // Dir Potentiometer (Davis sensor) in kOhm

#define UNDEFINED  -1           // Return code for undef
#define SHORT_ERR  -2           // Error code when a short is detected
#define OPEN_ERR   -3           // Error code when a open is detected

#define TEMP25    298.15        // Temp 25 ref for CTN
#define BETA     3988           // Beta Coeff of CTN TDK B57863S0103+040 https://docs.rs-online.com/6a46/0900766b813c0ed3.pdf

/*
* Threshold computation
*/

/* D2 IN, D0 OUT 0, READ A2 */
/* Peet bros detection*/
/* if speed switch open */
const int THR1=int(ADCFS*0.97);                                                            // 992
/* if speed switch closed */
const int THR_Peet_low = int(ADCFS/(1+RPULLUP/(2*RSERIAL)*(1+TOL)/(1-TOL)));               // 156
const int THR_Peet_hi  = int(ADCFS/(1+RPULLUP/(2*RSERIAL)*(1-TOL)/(1+TOL)));               // 185

/* Shenzen detection*/
const int THR_Shenzen_low = int(ADCFS/(1.0+RPULLUP/(2*RSERIAL+RSHENMIN)*(1+TOL)/(1-TOL))); // 200
const int THR_Shenzen_hi  = int(ADCFS/(1.0+RPULLUP/(2*RSERIAL+RSHENMAX)*(1-TOL)/(1+TOL))); // 952

/* Davis detection*/
const int THR_Davis_low = int(ADCFS/(1.0+RPULLUP/(RSERIAL+RDAVISPOT)*(1+TOL)/(1-TOL)));    // 670
const int THR_Davis_hi  = int(ADCFS/(1.0+RPULLUP/(RSERIAL+RDAVISPOT)*(1-TOL)/(1+TOL)));    // 714



/*
* This part of code is about packing data to comply with the format expected by OpenWindMap
*
* Numbers are arranged to fit into 8 bytes (2 periods, 4 data)
* xxx[0] -> data from T-12 to T-6 min
* xxx[1] -> data from T-6 min to T
* T being the time of emission
*/
typedef struct __attribute__ ((packed)) sigfox_wind_message {
        int8_t speedMin[2];
        int8_t speedAvg[2];
        int8_t speedMax[2];
        int8_t directionAvg[2];
        int8_t batVin;
        int8_t batVcc;
        int8_t temperature;
        int8_t version; 
} SigfoxWindMessage_t;


// wind speed encoding over 1 byte
// 
static uint8_t encodeWindSpeed (float speedKmh) {
  uint8_t encodedSpeed;
  if (speedKmh < 10.) {
    // 0 to 9.75 kmh : 0.25 km/h resolution
    encodedSpeed = (uint8_t)(float)(speedKmh * 4. + 0.5);
  } else if (speedKmh < 80.) {
    // 10 to 79.5 kmh  : 0.5 km/h resolution
    encodedSpeed = (uint8_t)(float)(speedKmh * 2. + 0.5) + 20;
  } else if (speedKmh < 120.) {
    // 80 to 119 kmh  : 1 km/h resolution
    encodedSpeed = (uint8_t)(float)(speedKmh + 0.5) + 100;
  } else if (speedKmh < 190.) {
    // 120 to 188 kmh  : 2 km/h resolution
    encodedSpeed = (uint8_t)(float)(speedKmh / 2. + 0.5) + 160;
  } else {
    // 190 or + : out of range
    encodedSpeed = 0xFF;
  }
  return encodedSpeed;
}
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

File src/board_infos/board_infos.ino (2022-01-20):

// 
// Once you have received your MKRFox1200, you want to know its ID
// to be able to regiter the board into the Sigfox backend.
// So run this code and read the IDs on the serial monitor
// 


#include <SigFox.h>

void setup() {
  Serial.begin(115200);
  while(!Serial) {};
  if (!SigFox.begin()) {
    Serial.println("Shield error or not present!");
    return;
  }

  String version = SigFox.SigVersion();
  String ID = SigFox.ID();
  String PAC = SigFox.PAC();
  // Display module informations
  Serial.println("MKRFox1200 Sigfox first configuration");
  Serial.println("SigFox FW version " + version);
  Serial.println("ID  = " + ID);
  Serial.println("PAC = " + PAC);
  Serial.println("");
  Serial.print("Module temperature: ");
  Serial.println(SigFox.internalTemperature());
  Serial.println("Register your board on https://backend.sigfox.com/activate with provided ID and PAC");
  delay(100);

  // Send the module to the deepest sleep
  SigFox.end();
}

void loop() {

}

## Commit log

2021-11-08 shenzen sensor ok
2021-11-10 added sensor detection
2021-11-29 controling sensor power to save current
2021-12-01 created hardware schematics, started pcb
    [Shield.kicad_pcb, Shield.sch, Wiring.sch]
2021-12-02 completed PCB, DRC OK
    [Shield.kicad_pcb, Shield.sch]
2021-12-03 added grounded backplane
    [Shield.kicad_pcb, Shield.sch]
2021-12-03 fixed holes position
    [Shield.kicad_pcb]
2021-12-03 added JLCPCB BOM file
    [Shield-BOM.csv]
2021-12-07 changed diode ref because missing in fab catalog
    [Shield-BOM.csv, Shield.kicad_pcb, Shield.sch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]
2022-01-18 finished sensors, temperature, admin report
2022-01-20 more documentation
    [Wiring.sch]
2022-03-24 changed power on Davis, added debug control from pin11
    [Shield.sch, Wiring.sch]
2022-04-13 fixed terrific bug on wind dir with Davis or Misol
    [davis.ino, firmware.ino]
2022-04-21 reorg sockets
    [Shield.kicad_pcb]
2022-04-21 Revert "updated soft version"
    This reverts commit ec333ab792278aeebab38000c117c2b14d257bda.
    [def.h, firmware.ino]
2022-04-22 modified hardware: position of sockets, points for external switch
    [BOM.csv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]
2022-10-28 little change to avoid compiler warning on char declaration
    [debug.ino]
2022-11-08 fix timing overflow due to var type, added debug infos
    [debug.ino, def.h, firmware.ino]
2022-11-22 trying to fix admin report dispatch
    [debug.ino, def.h, firmware.ino]
2022-12-12 more printing features added to getAdminReport.py
2023-01-23 fixed bug on speed mini introduced in last commit
    [debug.ino, firmware.ino, serialListen.py]
2023-07-28 removed reboot on sigfox failure
    [def.h, firmware.ino]
2024-10-28 fixed wiring schematic doc
    [Wiring.kicad_sch, Wiring.sch]
